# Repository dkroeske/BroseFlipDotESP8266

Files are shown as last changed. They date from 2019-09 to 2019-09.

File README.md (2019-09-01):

# BroseFlipDotESP8266

Few months ago I bought some very old and dirty Brose Vollmatrix displays also known as flip dot of disk displays. With the use of the internet I reverse engineered the internals and hooked up an ESP8266 board. Using an MQTT broker I'm able to display text and bitmaps (black and white e.g. 112x16 pixels). After some time the display will enter idle mode where is makes a nice clock. The display also contains a backlight that can be controlled using MQTT.

MQTT enabled Brose FlipDot

{
	"message": {
		"content": "DIEDERICH",
		"x": 0,
		"y": 0,
		"font": 2,
		"display_time": 20
	},
	"backlight": {
		"on": true
	}
}

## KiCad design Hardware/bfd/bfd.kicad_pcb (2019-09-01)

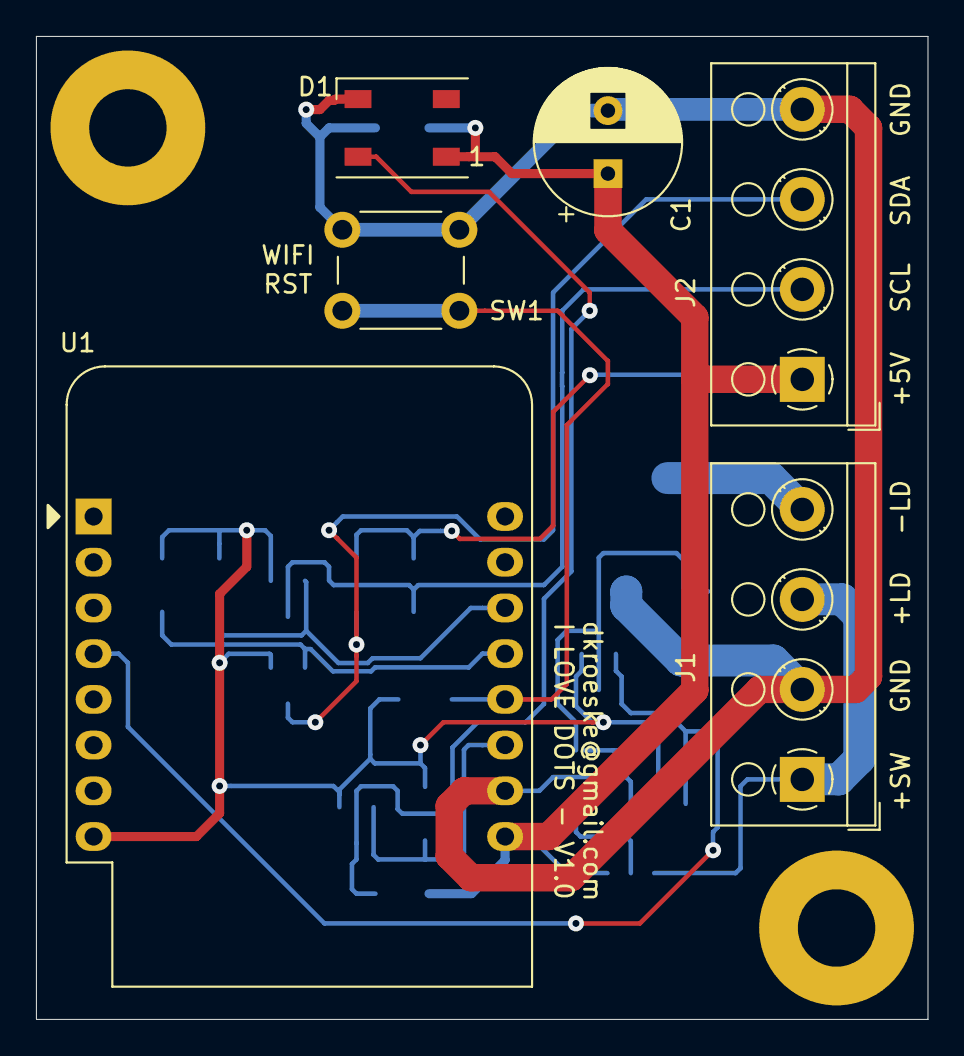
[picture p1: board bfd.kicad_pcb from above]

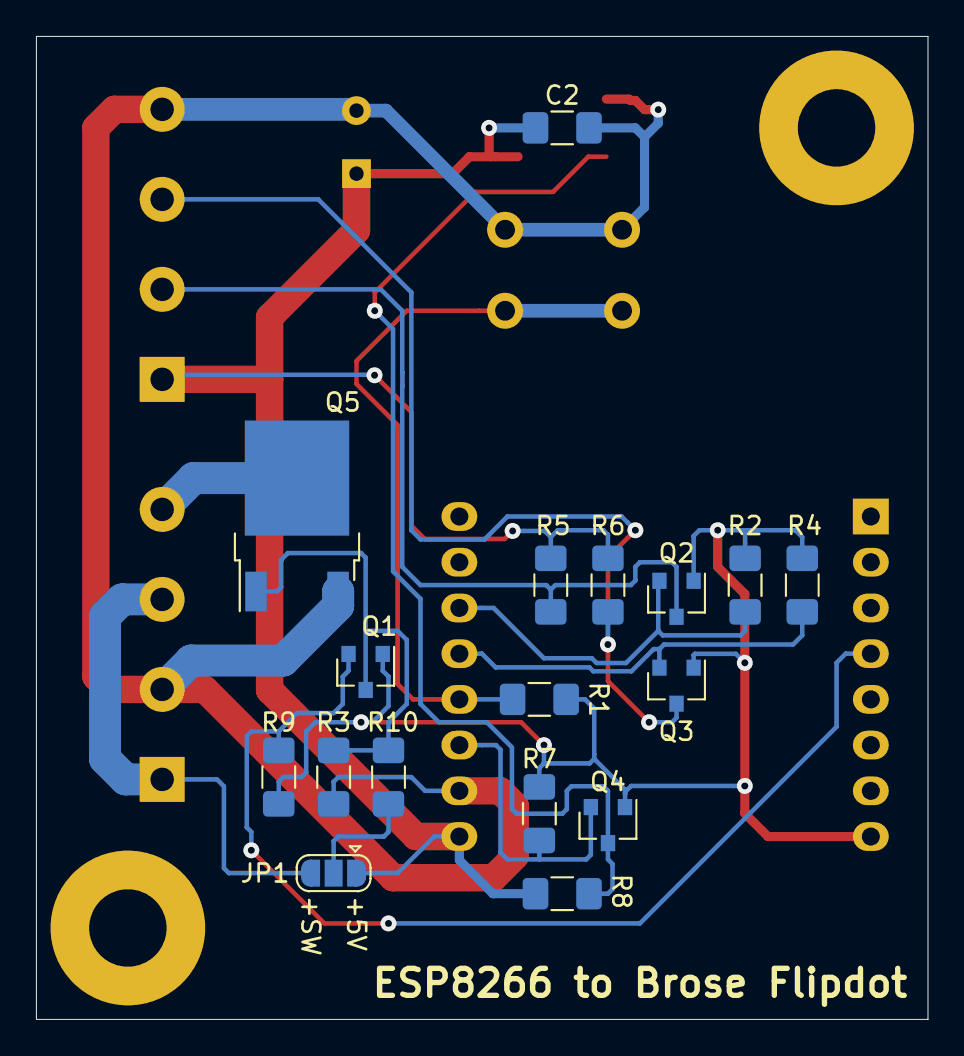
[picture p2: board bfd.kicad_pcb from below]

Board: 2 copper layers, 49.5 x 54.6 mm, 25 parts (17 on the bottom side), 15 nets.

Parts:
C1: 10uF/16V; CP_Radial_D8.0mm_P3.50mm
C2: 100nF; C_1206_3216Metric_Pad1.42x1.75mm_HandSolder
D1: WS2812B; LED_WS2812B_PLCC4_5.0x5.0mm_P3.2mm
H1, H2: MountingHole; MountingHole_4.3mm_M4_Pad
J1, J2: Screw_Terminal_01x04; TerminalBlock_RND_205-00003_1x04_P5.00mm_Horizontal
JP1: SolderJumper_3_Open; SolderJumper-3_P1.3mm_Open_RoundedPad1.0x1.5mm
Q1, Q2, Q3, Q4: BSS138; SOT-23
Q5: IRLR024N; TO-252-2
R1, R2, R3, R4, R5, R6, R7, R8, R9, R10: 10k; R_1206_3216Metric_Pad1.42x1.75mm_HandSolder
SW1: SW_DPST_x2; SW_PUSH_6mm
U1: WeMos_D1_mini; WEMOS_D1_mini_light

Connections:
+3V3: Q1.1, Q2.1, Q3.1, Q4.1, R1.1, R2.1, R4.1, R7.1, R9.1, U1.8
+5V: C1.1, C2.1, D1.1, J2.1, JP1.1, R5.1, R6.1, R8.1, U1.9
/BL: Q1.2, R9.2, U1.4
/LED: Q4.2, R7.2, U1.11
/RST: R1.2, SW1.2, U1.12
/SCL: Q2.2, R2.2, U1.14
/SCL_5V: J2.2, Q2.3, R5.2
/SDA: Q3.2, R4.2, U1.13
/SDA_5V: J2.3, Q3.3, R6.2
GND: C1.2, C2.2, D1.3, J1.2, J2.4, Q5.3, R3.2, SW1.1, U1.10
unnamed: D1.4, Q4.3, R8.2
unnamed: J1.1, J1.3, JP1.3
unnamed: J1.4, Q5.2
unnamed: JP1.2, R10.1
unnamed: Q1.3, Q5.1, R3.1, R10.2

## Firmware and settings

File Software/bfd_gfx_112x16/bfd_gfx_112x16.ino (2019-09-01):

/*-------------------------------------------------------------------------
  Arduino sketch to control a (old) Brose flipdot display (112x16 dots).

  See ... for more information.

  Written by dkroeske(dkroeske@gmail.com), august 2019

  Happy Coding
  
  -------------------------------------------------------------------------
  
  The MIT License (MIT)
  Copyright © 2019 <copyright Diederich Kroeske>
  
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
  -------------------------------------------------------------------------*/

//#define SECURE

#include <Adafruit_NeoPixel.h>

#include <WiFiManager.h>
#include <SPI.h>
#include <Wire.h>
#include <ESP8266WiFi.h>

#ifdef SECURE
  #include <WiFiClientSecure.h>
#else
  #include <WiFiClient.h>
#endif


#include <PubSubClient.h>
// MAKE SURE: in PubSubClient.h change MQTT_MAX_PACKET_SIZE to 2048 !! //

#include <ESP8266mDNS.h>
#include <ArduinoJson.h>
#include <time.h>
#include <string.h>
#include <simpleDSTadjust.h>

#include <WiFiUdp.h>
#include <ArduinoOTA.h>
#include <FS.h>

// WiFi RESET pin GPIO_0 (D3 wemos D1 Mini)
#define RST_PIN 0 // D3 on WeMos
#define BL_PIN 14 // D5 on WeMos
bool backlightAutoOff;          

#include <Adafruit_GFX.h>
#include "brose_fp_gfx.h"
#include "fonts/FlipDot7x8.h"
#include "fonts/FlipDot16x10.h"

// Neo pixel
#define NEOPIXELCOUNT   1     // Number of Neo pixels
#define NEOPIXELPORT    2     // Neo pixel GPIO2 (D4 wemos)

#define COLOR_SATURATION 255       // Neo pixel saturartion
#define COLOR_IDLE_BRIGHTNESS 10   // Neo pixel brightness when idle
#define COLOR_FLASH_BRIGHTNESS 120 // Neo pixel brightness when flashing
Adafruit_NeoPixel neoPixel(NEOPIXELCOUNT, NEOPIXELPORT, NEO_GRB + NEO_KHZ800);

const uint32_t COLOR_RED = neoPixel.Color(COLOR_SATURATION, 0, 0);
const uint32_t COLOR_GREEN = neoPixel.Color(0, COLOR_SATURATION, 0);
const uint32_t COLOR_BLUE = neoPixel.Color(0, 0, COLOR_SATURATION);
const uint32_t COLOR_WHITE = neoPixel.Color(COLOR_SATURATION, COLOR_SATURATION, COLOR_SATURATION);
const uint32_t COLOR_BLACK = neoPixel.Color(0,0,0);

// Local variables
WiFiManager wifiManager;

// Application configs struct. 
bool shouldSaveConfig;

#define MQTT_USERNAME_LENGTH       32
#define MQTT_PASSWORD_LENGTH       32
#define MQTT_ID_TOKEN_LENGTH       64
#define MQTT_TOPIC_STRING_LENGTH   64
#define MQTT_REMOTE_HOST_LENGTH   128
#define MQTT_REMOTE_PORT_LENGTH    10

typedef struct {
   char     mqtt_username[MQTT_USERNAME_LENGTH];
   char     mqtt_password[MQTT_PASSWORD_LENGTH];
   char     mqtt_id[MQTT_ID_TOKEN_LENGTH];
   char     mqtt_topic[MQTT_TOPIC_STRING_LENGTH];
   char     mqtt_remote_host[MQTT_REMOTE_HOST_LENGTH];
   char     mqtt_remote_port[MQTT_REMOTE_HOST_LENGTH];
} APP_CONFIG_STRUCT;

APP_CONFIG_STRUCT app_config;

#ifdef SECURE
const char *sha1_fingerprint = "4D:CE:F3:36:5B:A7:5C:3F:9D:B8:C1:F8:3F:C8:E5:4D:46:79:4D:8F";
const char* mqttUser = "";
const char* mqttPassword = "";
#endif

BroseFlipDot_28x16 flipdot = BroseFlipDot_28x16();

#ifdef SECURE
WiFiClientSecure wifiClient;
#else
WiFiClient wifiClient;
#endif

// Only with some dummy values seems to work ... instead of mqttClient();
PubSubClient mqttClient("", 0, wifiClient);

/* Prototype FSM functions. */
void start_pre(void);
void start_heartbeat(void);
void start_refresh(void);
void start_post(void);

void idle_pre(void);
void idle_heartbeat(void);
void idle_refresh(void);
void idle_post(void);

void mqtt_pre(void);
void mqtt_heartbeat(void);
void mqtt_refresh(void);
void mqtt_post(void);

/* Define FSM (states, events) */
typedef enum { EV_TRUE, EV_MQTT, EV_IDLE } ENUM_EVENT;
typedef enum { STATE_START, STATE_IDLE, STATE_MQTT } ENUM_STATE;

/* Define FSM transition */
typedef struct {
   void (*pre)(void);
   void (*heartbeat)(void);
   void (*refresh)(void);
   void (*post)(void);
   ENUM_STATE nextState;
} STATE_TRANSITION_STRUCT;

// Flipdot FSM definition (see statemachine diagram)
//
//        | EV_TRUE  EV_MQTT_MSG EV_IDLE
// -----------------------------------------------------------------
// START  | START    START       ILDE   Handle STARTUP      
// IDLE   | IDLE     MQTT        IDLE   Handle IDLE loop
// MQTT   | MQTT     MQTT        IDLE   Handle MQTT messages 
STATE_TRANSITION_STRUCT fsm[3][3] = {
  { 
    {start_pre, start_heartbeat, start_refresh, NULL, STATE_START},
    {start_pre, start_heartbeat, start_refresh, start_post, STATE_START},
    {start_pre, start_heartbeat, start_refresh, start_post, STATE_IDLE}
  },  // State START
  { 
    {idle_pre, idle_heartbeat, idle_refresh, idle_post, STATE_IDLE},
    {idle_pre, idle_heartbeat, idle_refresh, idle_post, STATE_MQTT},
    {idle_pre, idle_heartbeat, idle_refresh, idle_post, STATE_IDLE}
  },  // State IDLE
  { 
    {mqtt_pre, mqtt_heartbeat, mqtt_refresh, mqtt_post, STATE_MQTT},
    {mqtt_pre, mqtt_heartbeat, mqtt_refresh, mqtt_post, STATE_MQTT},
    {mqtt_pre, mqtt_heartbeat, mqtt_refresh, mqtt_post, STATE_IDLE}
  },  // State MQTT
};

// State holder
ENUM_STATE state;
ENUM_EVENT event;

// NTP server update interval (every hour)
#define NTP_UPDATE_INTERVAL_SEC 1000*60*60
uint32_t ntp_update_cur=0, ntp_update_prev=0;

// Heartbeat (polling)
#define HEARTBEAT_UPDATE_INTERVAL_SEC 1000 * 1
uint32_t heartbeat_cur=0, heartbeat_prev=0;

// (Display) refresh (polling)
#define REFRESH_UPDATE_INTERVAL_SEC 1000 * 60 * 5
uint32_t refresh_cur=0, refresh_prev=0;

// NTP time/date servers in NL
#define NTP_SERVERS "0.nl.pool.ntp.org", "1.nl.pool.ntp.org", "2.nl.pool.ntp.org"
#define timezone 1 // Central Europe, Time Zone (Amsterdam, the Netherlands)
struct dstRule StartRule = {"CEST", Last, Sun, Mar, 2, 3600};    // Daylight time = UTC/GMT +2 hours
struct dstRule EndRule = {"CET", Last, Sun, Oct, 1, 0};          // Standard time = UTC/GMT +1 hours
simpleDSTadjust dstAdjusted(StartRule, EndRule);

// Some LOGO displayed at boot
static const unsigned char PROGMEM ilovedots [] = {
0x00, 0x0f, 0xf0, 0x3c, 0x3c, 0x0f, 0xe0, 0x03, 0xf0, 0x3f, 0xff, 0x07, 0xe0, 0x00, 0x00, 0x0f, 
0xf0, 0x7e, 0x7e, 0x0f, 0xf8, 0x07, 0xf8, 0x3f, 0xff, 0x1f, 0xf0, 0x00, 0x00, 0x0f, 0xf0, 0xff, 
0xff, 0x0f, 0xfc, 0x0f, 0xfc, 0x3f, 0xff, 0x1f, 0xf0, 0x00, 0x00, 0x03, 0xc1, 0xe7, 0xe7, 0x8e, 
0x3e, 0x1f, 0x3e, 0x3f, 0xff, 0x3c, 0x30, 0x00, 0x00, 0x03, 0xc1, 0xc3, 0xc3, 0x8e, 0x1e, 0x1e, 
0x1e, 0x01, 0xe0, 0x3c, 0x10, 0x00, 0x00, 0x03, 0xc1, 0xc1, 0x83, 0x8e, 0x0f, 0x3c, 0x0f, 0x01, 
0xe0, 0x3e, 0x00, 0x00, 0x00, 0x03, 0xc1, 0xc0, 0x03, 0x8e, 0x0f, 0x3c, 0x0f, 0x01, 0xe0, 0x3f, 
0xc0, 0x00, 0x00, 0x03, 0xc1, 0xe0, 0x07, 0x8e, 0x0f, 0x3c, 0x0f, 0x01, 0xe0, 0x1f, 0xf0, 0x00, 
0x00, 0x03, 0xc0, 0xe0, 0x07, 0x0e, 0x0f, 0x3c, 0x0f, 0x01, 0xe0, 0x0f, 0xf0, 0x00, 0x00, 0x03, 
0xc0, 0xf0, 0x0f, 0x0e, 0x0f, 0x3c, 0x0f, 0x01, 0xe0, 0x03, 0xf8, 0x00, 0x00, 0x03, 0xc0, 0x78, 
0x1e, 0x0e, 0x0f, 0x3c, 0x0f, 0x01, 0xe0, 0x00, 0xf8, 0x00, 0x00, 0x03, 0xc0, 0x3c, 0x3c, 0x0e, 
0x1e, 0x1e, 0x1e, 0x01, 0xe0, 0x20, 0x78, 0x00, 0x00, 0x03, 0xc0, 0x3e, 0x7c, 0x0e, 0x3e, 0x1f, 
0x3e, 0x01, 0xe0, 0x30, 0x78, 0x00, 0x00, 0x0f, 0xf0, 0x0f, 0xf0, 0x0f, 0xfc, 0x0f, 0xfc, 0x01, 
0xe0, 0x3f, 0xf0, 0x00, 0x00, 0x0f, 0xf0, 0x07, 0xe0, 0x0f, 0xf8, 0x07, 0xf8, 0x01, 0xe0, 0x3f, 
0xe0, 0x00, 0x00, 0x0f, 0xf0, 0x01, 0x80, 0x0f, 0xe0, 0x03, 0xf0, 0x01, 0xe0, 0x0f, 0xc0, 0x00
};

// mqtt topic strings: flipdot/<uid>/msg and flipdot/<uid>/msg
char mqtt_topic_raw[128];
char mqtt_topic_msg[128];

// MQTT Message, command
typedef struct {
  uint8_t x, y;
  uint8_t font;
  char content[128];
  char display_time;
} BFD_MESSAGE;

typedef struct {
  bool on;
  bool autoOff;
} BFD_BACKLIGHT;

BFD_MESSAGE bfd_message = { 0, 0, '\0', 60 };
BFD_BACKLIGHT bfd_backlight = { false, true };

/******************************************************************/
void setup()
/* 
short   : Arduino setup                   
inputs  :        
outputs : 
notes   :         
Version : DMK, Initial code
*******************************************************************/
{

  // Init Serial port
  Serial.begin(115200);

  // Define I/O pins
  pinMode(RST_PIN, INPUT);

  // Backlight
  bl_init();
  
  // Setup unique mqtt id and mqtt topic string
  create_unique_mqtt_topic_string(app_config.mqtt_topic);
  create_unigue_mqtt_id(app_config.mqtt_id);
  sprintf(mqtt_topic_raw,"bfd/%s/raw",app_config.mqtt_topic);
  sprintf(mqtt_topic_msg,"bfd/%s/msg",app_config.mqtt_topic);
  
  // Init with red led
  smartLedInit(COLOR_RED);
  for(int idx = 0; idx < 25; idx++ ) {
    smartLedFlash();
    delay(100);
  }
  
  // Perform factory when reset
  // is pressed during powerup
  if( 0 == digitalRead(RST_PIN) ) {
    Serial.printf("RST pushbutton pressed, reset WiFiManager and appConfif settings\n");
    wifiManager.resetSettings();
    deleteAppConfig();
    while(0 == digitalRead(RST_PIN)) {
      smartLedShowColor(COLOR_RED);
      Serial.printf("Wait for user to release RST pin\n");
      delay(500);
    }
    ESP.reset();
  }

  // Read config file or generate default
  if( !readAppConfig(&app_config) ) {
    strcpy(app_config.mqtt_username, "");
    strcpy(app_config.mqtt_password, "");
    strcpy(app_config.mqtt_remote_host, "test.mosquitto.org");
    strcpy(app_config.mqtt_remote_port, "1883");
    writeAppConfig(&app_config);
  }

  // Setup WiFiManager
  smartLedShowColor(COLOR_BLUE);
  wifiManager.setMinimumSignalQuality(20);
  wifiManager.setTimeout(300);
  wifiManager.setSaveConfigCallback(saveConfigCallback);
  wifiManager.setDebugOutput(false);
  shouldSaveConfig = false;

  // Adds some parameters to the default webpage
  WiFiManagerParameter wmp_text("<br/>MQTT setting:</br>");
  wifiManager.addParameter(&wmp_text);
  WiFiManagerParameter custom_mqtt_username("mqtt_username", "Username", app_config.mqtt_username, MQTT_USERNAME_LENGTH);
  WiFiManagerParameter custom_mqtt_password("mqtt_password", "Password", app_config.mqtt_password, MQTT_PASSWORD_LENGTH);
  WiFiManagerParameter custom_mqtt_remote_host("mqtt_remote_host", "Host", app_config.mqtt_remote_host, MQTT_REMOTE_HOST_LENGTH);
  WiFiManagerParameter custom_mqtt_remote_port("mqtt_port", "Port", app_config.mqtt_remote_port, MQTT_REMOTE_PORT_LENGTH);
  wifiManager.addParameter(&custom_mqtt_username);
  wifiManager.addParameter(&custom_mqtt_password);
  wifiManager.addParameter(&custom_mqtt_remote_host);
  wifiManager.addParameter(&custom_mqtt_remote_port);

  // Add the unit ID to the webpage
  char fd_str[128]="<p>Your Flipdot ID: <b>";
  strcat(fd_str, app_config.mqtt_topic);
  strcat(fd_str, "</b> (You will need this later in the app)</p>");
  WiFiManagerParameter mqqt_topic_text(fd_str);
  wifiManager.addParameter(&mqqt_topic_text);

  // Start WiFiManager ...
  if( !wifiManager.autoConnect("Brose Flipdot Config")) {
    delay(1000);
    ESP.reset();
  }

  //
  // Update config if needed
  //
  if(shouldSaveConfig) {
    strcpy(app_config.mqtt_username, custom_mqtt_username.getValue());
    strcpy(app_config.mqtt_password, custom_mqtt_password.getValue());
    strcpy(app_config.mqtt_remote_host, custom_mqtt_remote_host.getValue());
    strcpy(app_config.mqtt_remote_port, custom_mqtt_remote_port.getValue());
    writeAppConfig(&app_config);
  }

  //
  Serial.printf("Setting MDNS service to 'brose_flipdot_v10'\n");
  if( !MDNS.begin("BROSE_FLIPDOT_V10") ) {
  } else {
    MDNS.addService("brose_flipdot_v10", "tcp", 10000);
  }

  // Sync to NTP service
  Serial.printf("Sync to time server\n");
  updateNTP();

  // Start OverTheAir update services
  ArduinoOTA.onStart([]() {
    String type;
    if (ArduinoOTA.getCommand() == U_FLASH)
      type = "sketch";
    else // U_SPIFFS
      type = "filesystem";

    // NOTE: if updating SPIFFS this would be the place to unmount SPIFFS using SPIFFS.end()
    Serial.println("Start updating " + type);
  });
  
  ArduinoOTA.onEnd([]() {
    Serial.println("\nEnd");
  });
  
  ArduinoOTA.onProgress([](unsigned int progress, unsigned int total) {
    Serial.printf("Progress: %u%%\r", (progress / (total / 100)));
  });
    
  ArduinoOTA.onError([](ota_error_t error) {
    Serial.printf("Error[%u]: ", error);
    if (error == OTA_AUTH_ERROR) Serial.println("Auth Failed");
    else if (error == OTA_BEGIN_ERROR) Serial.println("Begin Failed");
    else if (error == OTA_CONNECT_ERROR) Serial.println("Connect Failed");
    else if (error == OTA_RECEIVE_ERROR) Serial.println("Receive Failed");
    else if (error == OTA_END_ERROR) Serial.println("End Failed");
  });

  ArduinoOTA.begin();

  // Debug print
  Serial.printf("OAT ready\n");
  Serial.printf("mqtt_username: %s\n", app_config.mqtt_username);
  Serial.printf("mqtt_password: %s\n", app_config.mqtt_password);
  Serial.printf("mqtt_id: %s\n", app_config.mqtt_id);
  Serial.printf("mqtt_topic RAW: %s\n", mqtt_topic_raw);
  Serial.printf("mqtt_topic MSG: %s\n", mqtt_topic_msg);
  Serial.printf("mqtt_remote_host: %s\n", app_config.mqtt_remote_host);
  Serial.printf("mqtt_remote_port: %s\n", app_config.mqtt_remote_port);

  // Set statusled to GREEN
  smartLedInit(COLOR_GREEN);

  // Initialise FSM
  initFSM(STATE_START, EV_TRUE);

}

/******************************************************************/
void loop()
/* 
short   : Arduino loop                   
inputs  :        
outputs : 
notes   :         
Version : DMK, Initial code
*******************************************************************/
{

  // Check for IP connection
  if( WiFi.status() == WL_CONNECTED) {

    // Check for OTA firmware updates
    ArduinoOTA.handle();

    // Handle mqtt
    if( !mqttClient.connected() ) {
      mqtt_connect();
      delay(250);
    } else {
      // Handle MQTT loop
      mqttClient.loop();
    }
  } 

  // 
  // Sync time with NTP
  //
  if( WiFi.status() == WL_CONNECTED) {
    ntp_update_cur = millis();
    uint32_t ntp_update_elapsed = ntp_update_cur - ntp_update_prev;
    if( ntp_update_elapsed >= NTP_UPDATE_INTERVAL_SEC ) {
      ntp_update_prev = ntp_update_cur; 
      updateNTP();
    }
  }

  // 
  // Handle heartbeat (Ticker.h causes crashes)
  //
  heartbeat_cur = millis();
  uint32_t heartbeat_elapsed = heartbeat_cur - heartbeat_prev;
  if( heartbeat_elapsed >= HEARTBEAT_UPDATE_INTERVAL_SEC ) {
    
    //
    heartbeat_prev = heartbeat_cur; 
    
    // Call the heartbeat fp
    if( fsm[state][event].heartbeat != NULL) {
      fsm[state][event].heartbeat() ;
    } 
  }

  // 
  // Handle (display)refresh (Ticker.h causes crashes)
  //
  refresh_cur = millis();
  uint32_t refresh_elapsed = refresh_cur - refresh_prev;
  if( refresh_elapsed >= REFRESH_UPDATE_INTERVAL_SEC ) {
    
    //
    refresh_prev = refresh_cur; 

    // Call the refresh fp
    if( fsm[state][event].refresh != NULL) {
      fsm[state][event].refresh() ;
    } 
  }
}

/******************************************************************
*
* MQTT section
*
******************************************************************/

/******************************************************************/
void mqtt_callback(char* topic, byte* payload, unsigned int length)
/* 
short   : mqtt callback                  
inputs  :        
outputs : 
notes   :         
Version : DMK, Initial code
*******************************************************************/
{
  // 
  // Raw Message (pixels)
  // 
  if( 0 == strcmp(topic, mqtt_topic_raw) ) {
//
//    //
//    uint8_t buf[ DISPLAY_WIDTH * DISPLAY_HEIGHT/8 ];
//    uint8_t *pbuf = buf;
//    
//    DynamicJsonBuffer jsonBuffer(2048);
//    //StaticJsonBuffer<2048> jsonBuffer;
//    JsonObject& root = jsonBuffer.parseObject(payload);
//    if( root.success() ) {
//      JsonArray& pixels = root["pixels"]; 
//      for( JsonArray::iterator it = pixels.begin(); it!=pixels.end(); ++it) {
//        *pbuf++ = it->as<uint8_t>();
//      }
//    }
//    flipdot.directDrawBuffer(buf);
//    flipdot.display();
//
//    // Flash the pixel
//    smartLedFlash(colorFlashLevel);
  }

  // 
  // Normal Text
  // 
  if( 0 == strcmp(topic, mqtt_topic_msg) ) {

    DynamicJsonDocument jsonDocument(2048);
    DeserializationError error = deserializeJson(jsonDocument, payload);

    Serial.printf("**%s\n",error.c_str());
    
    if( !error ) {

      // Test for flipdot message
      JsonVariant msg = jsonDocument["message"];

      if(!msg.isNull()) {

        // Parse JSON  
        JsonVariant json_content = msg["content"];
          if(!json_content.isNull()) {
            strcpy(bfd_message.content, json_content.as<const char*>());
          } else {
            strcpy(bfd_message.content, "--()--");
        }

        JsonVariant json_pos_x = msg["x"];
        if(!json_pos_x.isNull()) {
          bfd_message.x = json_pos_x.as<uint8_t>();
        } else {
          bfd_message.x = 0;
        }

        JsonVariant json_pos_y = msg["y"];
        if(!json_pos_y.isNull()) {
          bfd_message.y = json_pos_y.as<uint8_t>();
        } else {
          bfd_message.y = 0;
        }

        JsonVariant json_font = msg["font"];
        bfd_message.font = 0;
        if(!json_font.isNull()) {
          bfd_message.font = json_font.as<uint8_t>();
        } else {
          bfd_message.font = 0;
        }

        JsonVariant json_display_time = msg["display_time"];
        if(!json_display_time.isNull()) {
          bfd_message.display_time = json_display_time.as<uint16_t>();
        } else {
          bfd_message.display_time = 20;
        }
      }

      // Test for flipdot command
      JsonVariant cmd = jsonDocument["backlight"];
      if(!cmd.isNull()) {

        // Test for BACKLIGHT ON/OFF
        JsonVariant json_on = cmd["on"];
        if(!json_on.isNull()) {
          if( json_on.as<bool>() == true ) {
            bfd_backlight.on = true;
          } else {
            bfd_backlight.on = false;
          }
        }

        // Test for BACKLIGHT AutoOff ON/OFF
        JsonVariant json_autoOff = cmd["autoOff"];
        if(!json_autoOff.isNull()) {
          if( json_autoOff.as<bool>() == true ) {
            bfd_backlight.autoOff = true;
          } else {
            bfd_backlight.autoOff = false;          
          }
        }
      }
    
      // Flash the pixel
      smartLedFlash();

      // Raise MQTT mode
      raiseEvent(EV_MQTT);
    }
  }
}


/******************************************************************
*
* FSM section
*
******************************************************************/

/******************************************************************/
void initFSM(ENUM_STATE new_state, ENUM_EVENT new_event)
/* 
short:         
inputs:        
outputs: 
notes:         
Version :      DMK, Initial code
*******************************************************************/
{
  // Set start state
  state = new_state;
  event = new_event;

  // and call event.pre
  if( fsm[state][event].pre != NULL) {
    fsm[state][event].pre() ;
  } 
}
 
/******************************************************************/
void raiseEvent(ENUM_EVENT new_event)
/* 
short:         
inputs:        
outputs: 
notes:         
Version :      DMK, Initial code
*******************************************************************/
{
  // call event.post
  if( fsm[state][event].post != NULL) {
    fsm[state][event].post() ;
  } 
  
  // Set new state
  ENUM_STATE new_state = fsm[state][new_event].nextState;
  
  // call newstate ev.pre
  if( fsm[new_state][new_event].pre != NULL) {
    fsm[new_state][new_event].pre() ;
  } 
  
  // Set new state
  state = new_state;
  
  // Store new event
  event = new_event;
}

/******************************************************************
*
* FSM callbacks section
*
******************************************************************/

/******************************************************************/
void start_pre(void){
  Serial.print("START: pre() ...\n");

  // Display important info at startup (on flipdot)
  bl_on();
  flipdot_display_powerup();
  bl_off();
  
  // Enter idle mode
  raiseEvent(EV_IDLE);
}

/******************************************************************/
void start_heartbeat(void){
  Serial.print("START: heartbeat ...\n");
}

/******************************************************************/
void start_refresh(void){
  Serial.print("START: refresh ...\n");
}

/******************************************************************/
void start_post(void){
  Serial.print("START: post() ...\n");
}

/******************************************************************/
void idle_pre(void){
  //Serial.print("IDLE: pre() ...\n");
}

/******************************************************************/
void idle_heartbeat(void){
  //Serial.print("IDLE: heartbeat ...\n");
  flipdot_display_idle();
}

/******************************************************************/
void idle_refresh(void){
  Serial.print("IDLE: refresh ...\n");
  flipdot_display_refresh();
}

/******************************************************************/
void idle_post(void){
  Serial.print("IDLE: post() ...\n");
}
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

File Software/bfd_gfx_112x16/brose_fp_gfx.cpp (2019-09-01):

/*********************************************************************
  This is a library for Brose Flipdot Matrix displays

  These displays use I2C to communicate, 2 are required to  
  interface

  Using the Adafruit gfx library. Big thanx, Adafruit Industries!

  -------------------------------------------------------------------------
  
  The MIT License (MIT)
  Copyright © 2019 <copyright Diederich Kroeske>
  
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
*********************************************************************/


#ifdef __AVR__
  #include <avr/pgmspace.h>
#elif defined(ESP8266)
 #include <pgmspace.h>
#else
 #define pgm_read_byte(addr) (*(const unsigned char *)(addr))
#endif

#if !defined(__ARM_ARCH) && !defined(ENERGIA) && !defined(ESP8266)
 #include <util/delay.h>
#endif

#include <stdlib.h>
#include <Adafruit_GFX.h>
#include "brose_fp_gfx.h"

const int I2C_SCL_PIN = D1;
const int I2C_SDA_PIN = D2;

#define swap(a, b) { int16_t t = a; a = b; b = t; }

uint8_t buffer[2][DISPLAY_WIDTH * DISPLAY_HEIGHT / 8];
//uint8_t display_buffer[DISPLAY_WIDTH * DISPLAY_HEIGHT / 8] = {0,};
uint8_t *displayPtr;
uint8_t *bufferPtr;

BroseFlipDot_28x16::BroseFlipDot_28x16() : Adafruit_GFX(DISPLAY_WIDTH, DISPLAY_HEIGHT) {
  
  displayPtr = buffer[0];
  bufferPtr = buffer[1];
  memset(bufferPtr, 0x00, (DISPLAY_WIDTH * DISPLAY_HEIGHT/8));
  memset(displayPtr, 0xFF, (DISPLAY_WIDTH * DISPLAY_HEIGHT/8));

  //Wire.begin(I2C_SDA_Pin, I2C_SCL_Pin);
  brzo_i2c_setup(I2C_SDA_PIN, I2C_SCL_PIN, 200);
  i2c_tx(0x20, 0x00);
  i2c_tx(0x21, 0x00);
  i2c_tx(0x22, 0x00);
}  

//
//
//
void BroseFlipDot_28x16::directDrawBuffer( const uint8_t *buffer ) {
  memcpy(bufferPtr, buffer, (DISPLAY_WIDTH * DISPLAY_HEIGHT/8));
}


//
//
//
void BroseFlipDot_28x16::drawPixel(int16_t x, int16_t y, uint16_t color) {
  if ((x < 0) || (x >= width()) || (y < 0) || (y >= height()))
    return;

  // check rotation, move pixel around if necessary
  switch (getRotation()) {
  case 1:
    swap(x, y);
    x = WIDTH - x - 1;
    break;
  case 2:
    x = WIDTH - x - 1;
    y = HEIGHT - y - 1;
    break;
  case 3:
    swap(x, y);
    y = HEIGHT - y - 1;
    break;
  }

  // x is which column
  switch (color)
  {
    case BLACK:   *(bufferPtr + x + (y/8)*DISPLAY_WIDTH) |=  (1 << (y&7)); break;
    case WHITE:   *(bufferPtr + x + (y/8)*DISPLAY_WIDTH) &= ~(1 << (y&7)); break;
    case INVERSE: *(bufferPtr + x + (y/8)*DISPLAY_WIDTH) ^=  (1 << (y&7)); break;
  }
}

//
//
// 
void BroseFlipDot_28x16::invertDisplay(void) {
  for( uint8_t y = 0; y < (DISPLAY_WIDTH * DISPLAY_HEIGHT / 8); y++ ) {
    (*(bufferPtr+y))^=0xFF;
    yield();
  }  
}

//
//
//
void BroseFlipDot_28x16::display(void) {

  for( uint8_t y = 0; y < (DISPLAY_WIDTH * DISPLAY_HEIGHT / 8); y++ ) {
    uint8_t row = 8 * (y / DISPLAY_WIDTH);
    uint8_t colomn = y % DISPLAY_WIDTH;
    
    uint8_t new_pixel = *(bufferPtr + y);
    uint8_t prev_pixel = *(displayPtr + y);

    if( prev_pixel != new_pixel ) {
      for (uint8_t b = 0; b < 8; b++) {
        flipDot(((new_pixel >> b) & 0x01), row + b, colomn);
      }
    }

    // Update displayPtr with new
    *(displayPtr + y) = new_pixel;
    
    // Prevent WD reset
    yield();
  }

  // Switch off all fp2800 drivers
  i2c_tx(0x20, 0x00);
  i2c_tx(0x21, 0x00);
  i2c_tx(0x22, 0x00);
}

//
//
//
void BroseFlipDot_28x16::clearDisplay(void) {
  memset(bufferPtr, 0x00, (DISPLAY_WIDTH * DISPLAY_HEIGHT/8));
}

//
//
//
void BroseFlipDot_28x16::setDisplay(void) {
  memset(bufferPtr, 0xFF, (DISPLAY_WIDTH * DISPLAY_HEIGHT/8));
}

//
//
//
void BroseFlipDot_28x16::flipDot(boolean set, uint8_t row, uint8_t col) {

    uint8_t row_lut[] = {
      0x02, 0x01, 0x03, 0x04, 0x06, 0x05, 0x07, 0x0A, 0x09, 0x0B, 0x0C, 0x0E, 0x0D, 0xFF,
      0x02, 0x01, 0x03, 0x04, 0x06, 0x05, 0x07, 0x0A, 0x09, 0x0B, 0x0C, 0x0E, 0x0D, 0xFF,
    };

    uint8_t col_lut[] = {
      (4 << 2) | 0x00, (2 << 2) | 0x00, (6 << 2) | 0x00, (1 << 2) | 0x00, (5 << 2) | 0x00, (3 << 2) | 0x00, (7 << 2) | 0x00,
      (4 << 2) | 0x02, (2 << 2) | 0x02, (6 << 2) | 0x02, (1 << 2) | 0x02, (5 << 2) | 0x02, (3 << 2) | 0x02, (7 << 2) | 0x02,
      (4 << 2) | 0x01, (2 << 2) | 0x01, (6 << 2) | 0x01, (1 << 2) | 0x01, (5 << 2) | 0x01, (3 << 2) | 0x01, (7 << 2) | 0x01,
      (4 << 2) | 0x03, (2 << 2) | 0x03, (6 << 2) | 0x03, (1 << 2) | 0x03, (5 << 2) | 0x03, (3 << 2) | 0x03, (7 << 2) | 0x03,
    };

    uint8_t reg_data = row_lut[row];
    uint8_t de_set = 0x30;
    uint8_t de_clr = 0x28;

    if( row >= 14 ) {
        de_set = 0xC0;
        de_clr = 0x88;
    }

    /* 
     * Get from LUT a0, a1, a2 and b1 for fp2800a (i2c addr: 0x22)
     * (b0 is used to select clr.)
     * 
     */
    uint8_t a0a1 = (reg_data & 0x03) >> 0;
    uint8_t a2 = (reg_data & 0x04) >> 2;
    uint8_t b1 = (reg_data & 0x08) >> 3;

    /* 
     *  Set fp2800a (i2c addr = 0x22) to select row.
     */
    uint8_t b;
    if(set) {
      b = de_set | a0a1 | (b1 << 2); // E = 1, D = 1, b0 = 0;
    }
    else {
      b = de_clr | a0a1 | (b1 << 2); // E = 1, D = 0, b0 = 1;
    }
    i2c_tx(0x22, b);

    /*
     * Set fp2800a (i2c addr = 0x01) to select colomn.
     * (P7 is used to select a2 for row select).
     *
     */
    uint8_t c;
    if(set) {
      c = (a2 << 7) | (0 << 6) | (col_lut[col%28] << 1); // D = 0
    }
    else {
      c = (a2 << 7) | (1 << 6) | (col_lut[col%28] << 1); // D = 1
    }
    i2c_tx(0x21, c);

    // Strobe colomn (i2c addr = 0x00) (E pin 1->0)
    for(uint8_t idx = 0; idx < 1; idx++) {
      
      switch( col / 28) {
        case 0:
          i2c_tx(0x20, 0xFE); // Panel 1: 1111 1110
          break;
        case 1:
          i2c_tx(0x20, 0xFD); // Panel 2: 1111 1101
          break;
        case 2:
          i2c_tx(0x20, 0xFB); // Panel 3: 1111 1011
          break;
        case 3:
          i2c_tx(0x20, 0xF7); // Panel 4: 1111 0111
          break;
      }
      delayMicroseconds(600);

      switch( col / 28) {
        case 0:
          i2c_tx(0x20, 0x7E); // Panel 1: 1111 1110
          break;
        case 1:
          i2c_tx(0x20, 0x7D); // Panel 2: 1111 1101
          break;
        case 2:
          i2c_tx(0x20, 0x7B); // Panel 3: 1111 1011
          break;
        case 3:
          i2c_tx(0x20, 0x77); // Panel 5: 1111 0111
          break;
      }
      //delayMicroseconds(400);
    }
}

void BroseFlipDot_28x16::i2c_tx(uint8_t addr, uint8_t data) {
  brzo_i2c_start_transaction(addr, 400);
  brzo_i2c_write(&data, 1, false);
  brzo_i2c_end_transaction();
}
